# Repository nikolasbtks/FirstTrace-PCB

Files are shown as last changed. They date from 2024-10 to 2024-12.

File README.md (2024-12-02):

# FirstTrace

## Description

This project demonstrates a custom 2-layer PCB containing the STM32F103C8T6 microcontroller. This board can be used for embedded development using GPIO and SWD Headers.

## Components

1. Microcontroller: STM32F103C8T6
   - 20 KB SRAM and 64 KB Flash
   - 72 MHz clock speed 
   
2. USB Connectivity:
   - USB Micro-B for data and power 
   - USBLC6-2SC6 for ESD protection

3. Power Supply: AMS1117-3.3 
   - Voltage regulator for stable 3.3V output
  
4. Headers:
   - SWD headers for debugging and programming
   - GPIO headers for external connections
 
5. External Crystal Clock:
   - 16 MHz clock speed

## Disclaimer

This project is currently in **testing phase**. The provided documentation is shared for prototyping and learning purposes. If you choose to manufacture and use the board, please proceed with care, as it has not yet been fully validated.

## Schematic and PCB Design

The board was designed using KiCad. Files from the PCB design can be found in the **hardware** folder for board manufacture. This folder includes:

- PCB Schematic 
- PCB Layout
- Gerber files
- Assembly files

Below is a 3D render of the PCB design:
FirstTrace

## How to Use

1. Power the board
   - Use a USB Micro cable to power the board.
   
2. Microcontroller Programming:
   - Use STM32CubeIDE to program the microcontroller.
   - Use an SWD debugger, such as ST-Link, to the SWD headers.

3. GPIO Access
   - Use the GPIO headers to connect peripherals.

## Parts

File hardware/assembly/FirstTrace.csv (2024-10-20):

Reference | Value | Datasheet | Footprint | Qty | DNP
C1,C2,C3,C4,C6 | 100n | ~ | Capacitor_SMD:C_0402_1005Metric | 5
C5 | 4.7u | ~ | Capacitor_SMD:C_0603_1608Metric | 1
C7,C8 | 10p | ~ | Capacitor_SMD:C_0402_1005Metric | 2
C9 | 10n | ~ | Capacitor_SMD:C_0402_1005Metric | 1
C10,C11 | 1u | ~ | Capacitor_SMD:C_0402_1005Metric | 2
C12,C13 | 22u | ~ | Capacitor_SMD:C_0805_2012Metric | 2
D1 | Green LED | ~ | LED_SMD:LED_0603_1608Metric | 1
F1 | 500mA | ~ | Fuse:Fuse_0402_1005Metric | 1
FB1 | FerriteBead | ~ | Inductor_SMD:L_0603_1608Metric | 1
J1 | USB_B_Micro | ~ | Connector_USB:USB_Micro-B_Wuerth_629105150521 | 1
J2,J4 | Conn_01x04_Pin | ~ | Connector_PinHeader_2.54mm:PinHeader_1x04_P2.54mm_Vertical | 2
J3 | Conn_01x09_Pin | ~ | Connector_PinHeader_2.54mm:PinHeader_1x09_P2.54mm_Vertical | 1
J5 | Conn_01x10_Pin | ~ | Connector_PinHeader_2.54mm:PinHeader_1x10_P2.54mm_Vertical | 1
R1 | 10k | ~ | Resistor_SMD:R_0402_1005Metric | 1
R2 | 1k5 | ~ | Resistor_SMD:R_0402_1005Metric | 1
R3 | 100R | ~ | Resistor_SMD:R_0603_1608Metric | 1
SW1 | SW_SPDT | ~ | Button_Switch_THT:SW_E-Switch_EG1224_SPDT_Angled | 1
U1 | STM32F103C8Tx | https://www.st.com/resource/en/datasheet/stm32f103c8.pdf | Package_QFP:LQFP-48_7x7mm_P0.5mm | 1
U2 | USBLC6-2SC6 | https://www.st.com/resource/en/datasheet/usblc6-2.pdf | Package_TO_SOT_SMD:SOT-23-6 | 1
U3 | AMS1117-3.3 | http://www.advanced-monolithic.com/pdf/ds1117.pdf | Package_TO_SOT_SMD:SOT-223-3_TabPin2 | 1
Y1 | 16MHz | ~ | Crystal:Crystal_SMD_3225-4Pin_3.2x2.5mm | 1

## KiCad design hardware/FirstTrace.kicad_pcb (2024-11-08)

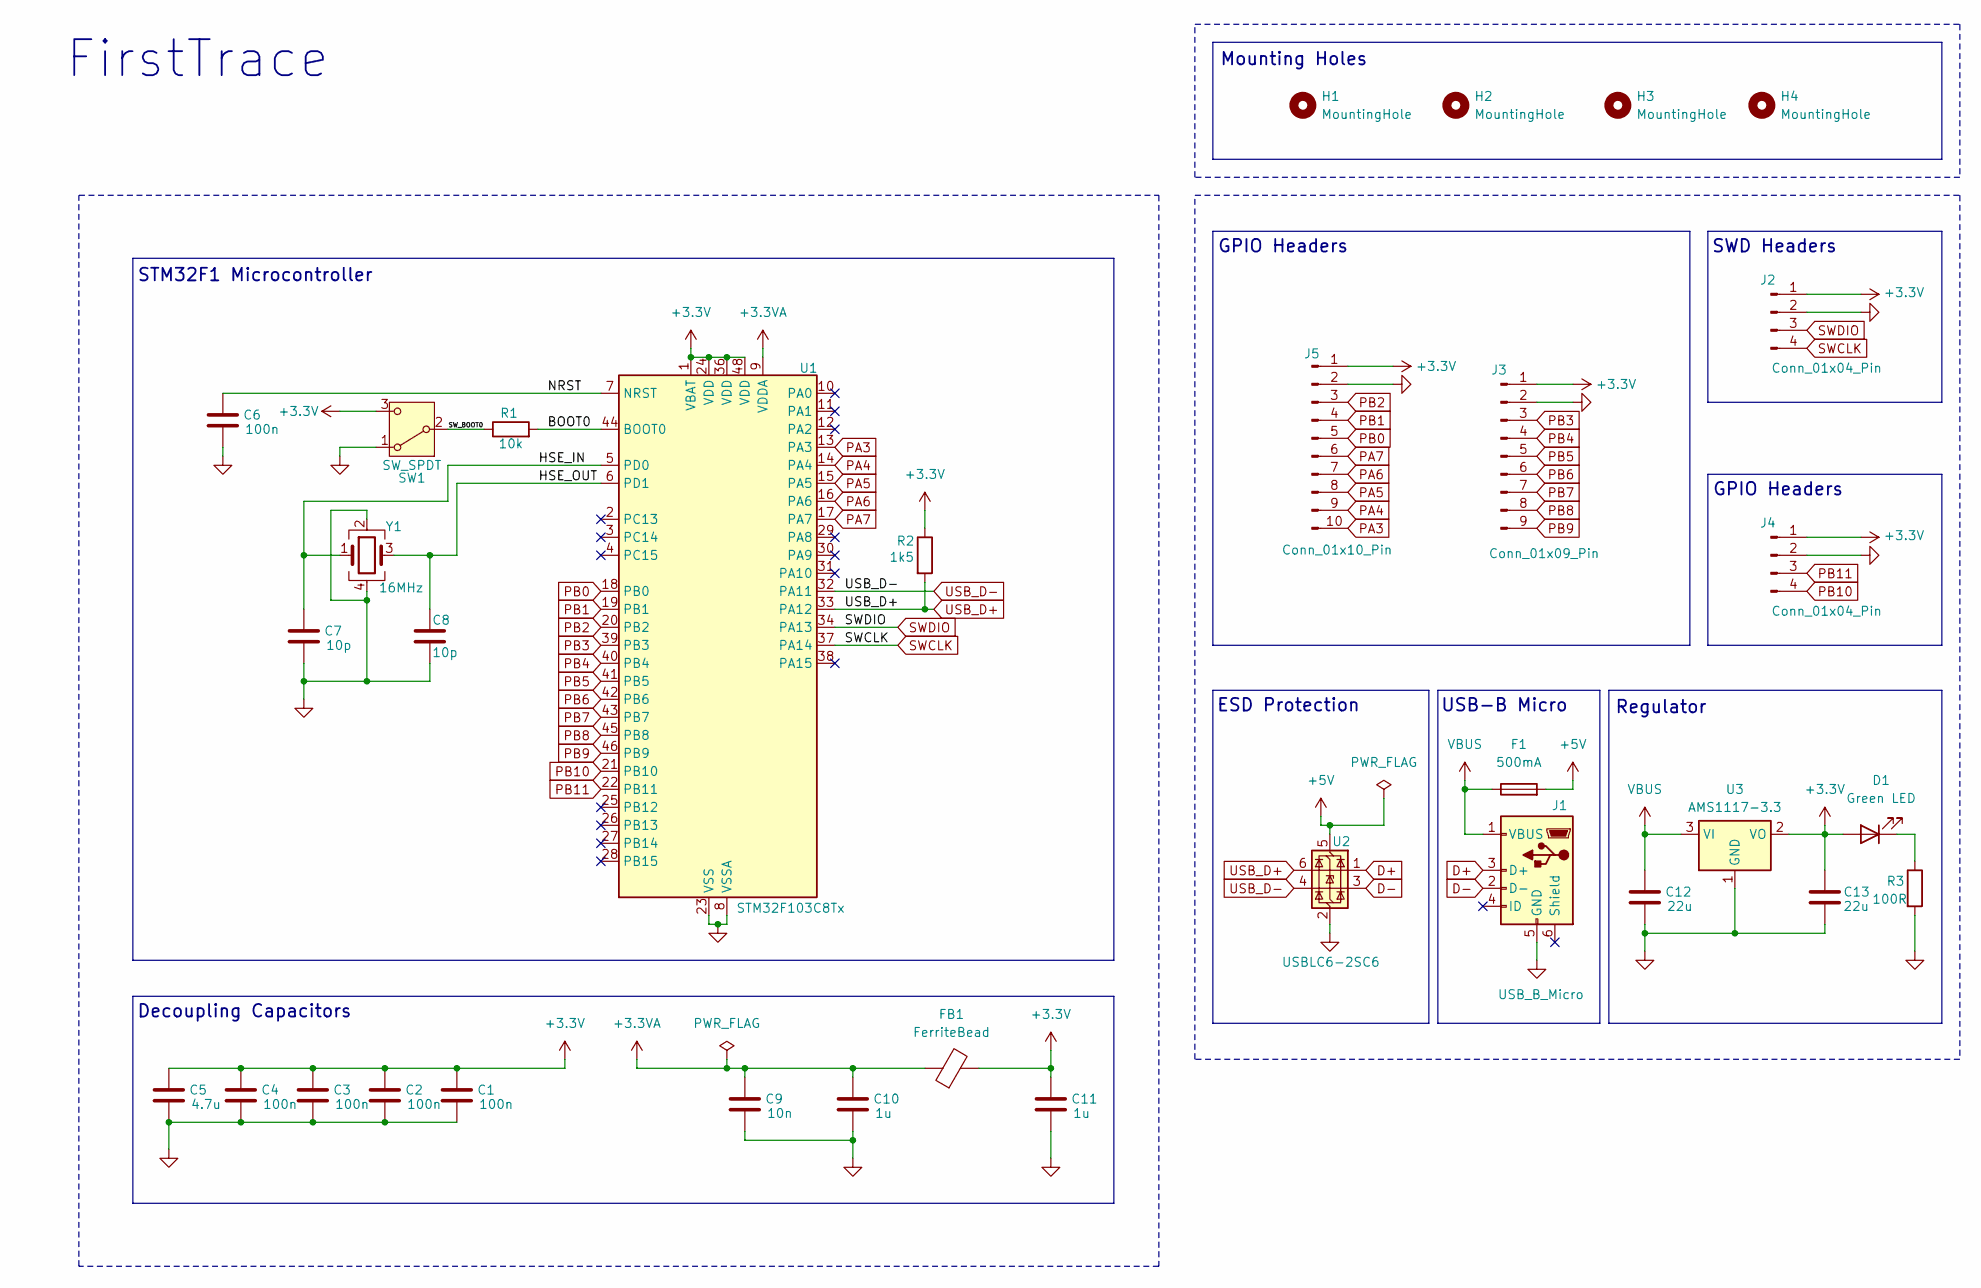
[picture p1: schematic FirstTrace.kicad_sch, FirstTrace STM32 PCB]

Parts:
C1, C2, C3, C4, C6: 100n; C_0402_1005Metric
C5: 4.7u; C_0603_1608Metric
C7, C8: 10p; C_0402_1005Metric
C9: 10n; C_0402_1005Metric
C10, C11: 1u; C_0402_1005Metric
C12, C13: 22u; C_0805_2012Metric
D1: Green LED; LED_0603_1608Metric
F1: 500mA; Fuse_0402_1005Metric
FB1: FerriteBead; L_0603_1608Metric
H1, H2, H3, H4: MountingHole; MountingHole_2.2mm_M2
J1: USB_B_Micro; USB_Micro-B_Wuerth_629105150521
J2, J4: Conn_01x04_Pin; PinHeader_1x04_P2.54mm_Vertical
J3: Conn_01x09_Pin; PinHeader_1x09_P2.54mm_Vertical
J5: Conn_01x10_Pin; PinHeader_1x10_P2.54mm_Vertical
R1: 10k; R_0402_1005Metric
R2: 1k5; R_0402_1005Metric
R3: 100R; R_0603_1608Metric
SW1: SW_SPDT; SW_E-Switch_EG1224_SPDT_Angled
U1: STM32F103C8Tx; LQFP-48_7x7mm_P0.5mm
U2: USBLC6-2SC6; SOT-23-6
U3: AMS1117-3.3; SOT-223-3_TabPin2
Y1: 16MHz; Crystal_SMD_3225-4Pin_3.2x2.5mm

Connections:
+3.3V: C1.1, C2.1, C3.1, C4.1, C5.1, C11.1, C13.1, D1.2 (A), FB1.2, J2.1, J3.1, J4.1, J5.1, R2.1, SW1.3 (C), U1.1 (VBAT), U1.24 (VDD), U1.36 (VDD), U1.48 (VDD), U3.2 (VO)
+3.3VA: C9.1, C10.1, FB1.1, U1.9 (VDDA)
+5V: F1.2, U2.5 (VBUS)
/BOOT0: R1.2, U1.44 (BOOT0)
/HSE_IN: C7.1, U1.5 (PD0), Y1.1
/HSE_OUT: C8.1, U1.6 (PD1), Y1.3
/NRST: C6.1, U1.7 (NRST)
/SW_BOOT0: R1.1, SW1.2 (B)
D+: J1.3 (D+), U2.1 (I/O1)
D-: J1.2 (D-), U2.3 (I/O2)
GND: C1.2, C2.2, C3.2, C4.2, C5.2, C6.2, C7.2, C8.2, C9.2, C10.2, C11.2, C12.2, C13.2, J1.5 (GND), J2.2, J3.2, J4.2, J5.2, R3.2, SW1.1 (A), U1.8 (VSSA), U1.23 (VSS), U1.35 (VSS), U1.47 (VSS), U2.2 (GND), U3.1 (GND), Y1.2, Y1.4
unnamed: D1.1 (K), R3.1
PA3: J5.10, U1.13 (PA3)
PA4: J5.9, U1.14 (PA4)
PA5: J5.8, U1.15 (PA5)
PA6: J5.7, U1.16 (PA6)
PA7: J5.6, U1.17 (PA7)
PB0: J5.5, U1.18 (PB0)
PB1: J5.4, U1.19 (PB1)
PB2: J5.3, U1.20 (PB2)
PB3: J3.3, U1.39 (PB3)
PB4: J3.4, U1.40 (PB4)
PB5: J3.5, U1.41 (PB5)
PB6: J3.6, U1.42 (PB6)
PB7: J3.7, U1.43 (PB7)
PB8: J3.8, U1.45 (PB8)
PB9: J3.9, U1.46 (PB9)
PB10: J4.4, U1.21 (PB10)
PB11: J4.3, U1.22 (PB11)
SWCLK: J2.4, U1.37 (PA14)
SWDIO: J2.3, U1.34 (PA13)
USB_D+: R2.2, U1.33 (PA12), U2.6 (I/O1)
USB_D-: U1.32 (PA11), U2.4 (I/O2)
VBUS: C12.1, F1.1, J1.1 (VBUS), U3.3 (VI)

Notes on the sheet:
FirstTrace
STM32F1 Microcontroller
SWD Headers
GPIO Headers
Regulator
Decoupling Capacitors
USB-B Micro
ESD Protection
Mounting Holes

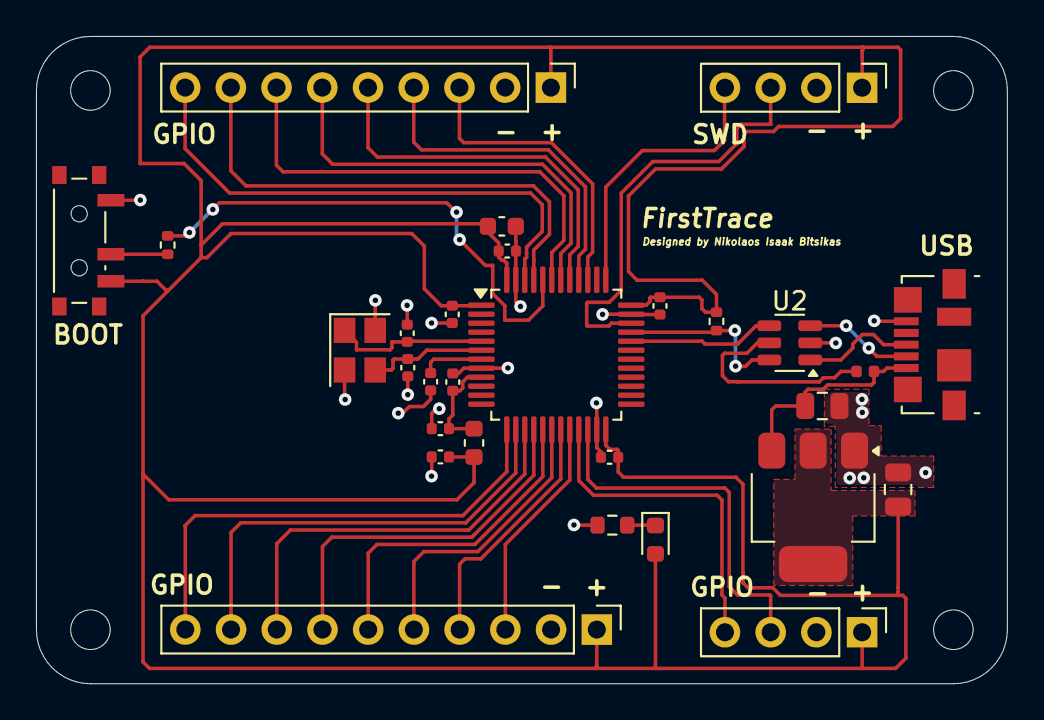
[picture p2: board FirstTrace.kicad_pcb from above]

Board: 2 copper layers, 53.9 x 36.0 mm, 33 parts (0 on the bottom side), 34 nets.
